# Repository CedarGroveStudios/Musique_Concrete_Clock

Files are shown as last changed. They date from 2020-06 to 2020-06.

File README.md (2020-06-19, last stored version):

# Musique_Concrete_Clock

### RTC-based hybrid cuckoo clock using heirloom sound components, powered by CircuitPython.

Uses a custom Cedar Grove StemmaHost FeatherWing as well as the __CedarGroveStudios/Unit_Converter__ and __CedarGroveStudios/Clock_Builder__ custom CircuitPython libraries.

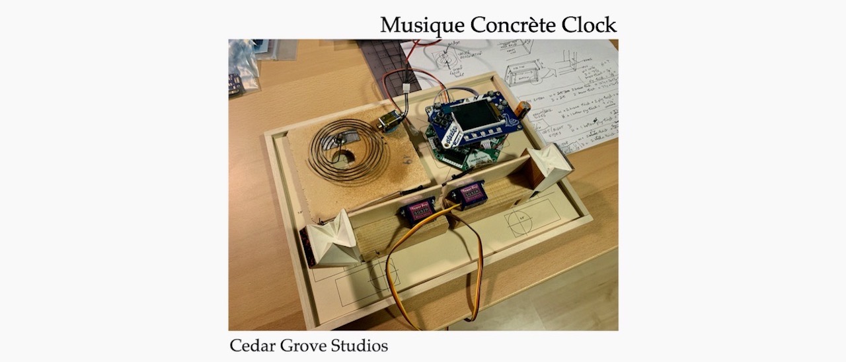
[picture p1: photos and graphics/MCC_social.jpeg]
Musique Concrète Clock


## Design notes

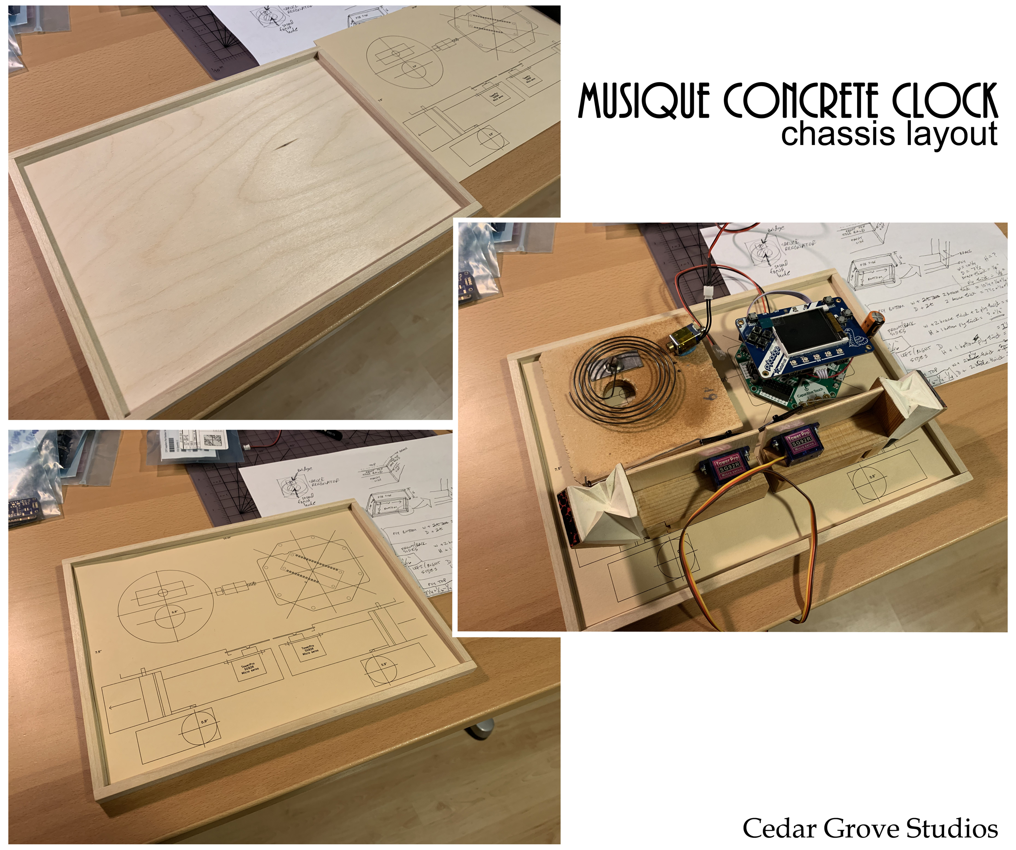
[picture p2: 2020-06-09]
photos and graphics/chassis_combo_a.jpg

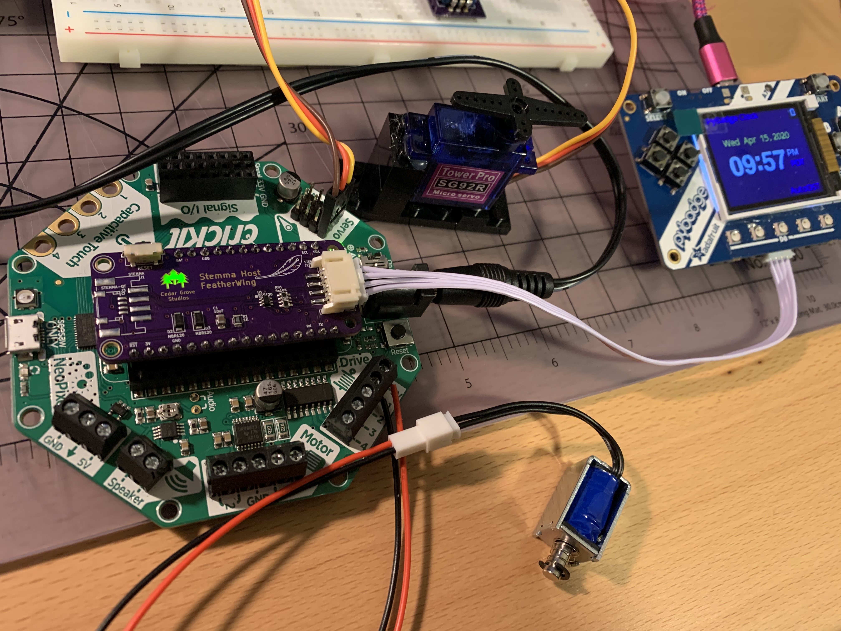
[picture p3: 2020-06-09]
photos and graphics/IMG_0154(Edited).jpg

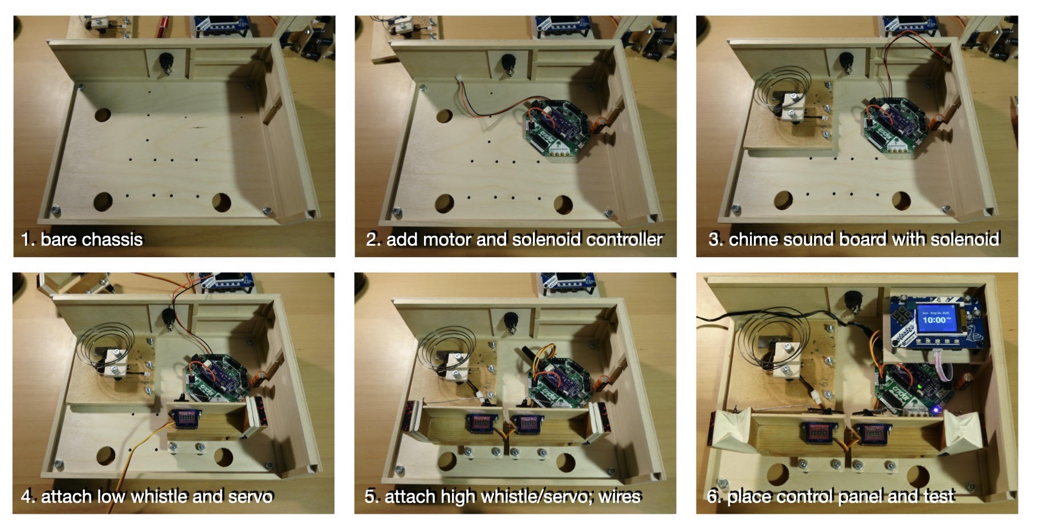
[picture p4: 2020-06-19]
photos and graphics/2020-05-24_MCC_composite.jpeg

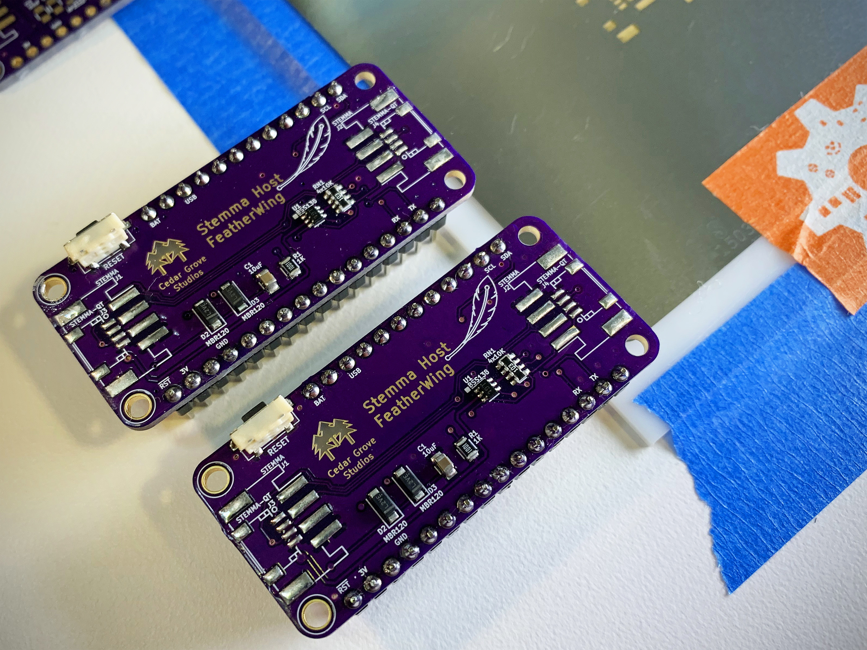
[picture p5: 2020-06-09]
photos and graphics/IMG_0151a.jpg

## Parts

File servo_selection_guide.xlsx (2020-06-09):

Servo Selection Guide
 | Vendor | PID | Price | Make | Model | Size | Gear | Analog FB | Continuous | Deg Rotation | Voltage | Current: Running (mA) | Current: Stall (mA) | Speed (sec/60deg) | Torque (kg-cm) | RPM (no load) | Auto-off
 | Adafruit | 169 | $5.95 | TowerPro | SG92R | Micro | Plastic |  |  | 180 | 4.8v (3-6v) |  |  | 0.10 | 2.50 | 200 | Y
 | Adafruit | 2201 | $5.95 | TowerPro | SG51R | Sub-Micro | Plastic |  |  | 180 | 4.8v (3-6v) |  |  | 0.10 | 0.60 | 200
 | Adafruit | 1143 | $9.95 | TowerPro | MG90D | Micro | Metal |  |  | 90 | 4.8v-6v |  |  | 0.10 | 2.10 | 200 | N
 | Adafruit | 1449 | $9.95 | Datan | S1123 | Micro | Plastic | X |  | 180 | 6v |  |  | 0.10 | 1.60 | 200
 | Adafruit | 1450 | $14.95 | Datan | B2122 | Micro | Metal | X |  | 120 | 6v |  |  | 0.10 | 1.80 | 200
 | Adafruit | 2307 | $11.95 | TowerPro | MG92B | Micro | Metal |  |  | 180 | 5v |  |  | 0.13 | 3.10 | 153.8461538
 | Adafruit | 154 | $11.95 | FeeTech | FS5103R | Standard | ? |  | X |  | 4.8v-6v |  |  | 0.18 | 3.00 | 111.1111111
 | Adafruit | 155 | $12.00 | TowerPro | SG-5010 | Standard | Plastic |  |  | 180 | 4.8v-6v |  |  | 0.20 | 5.50 | 100
 | Adafruit | 1142 | $19.95 | TowerPro | MG995R | Standard | Metal |  |  | 120 | 4.8v-6v |  |  | 0.20 | 8.50 | 100
 | Adafruit | 1404 | $14.95 | Datan | S1213 | Standard | ? | X |  | 180 | ? |  |  | 0.21 | 6.50 | 95.23809524
 | Adafruit | 2442 | $7.50 | TowerPro | FS90R | Micro | Plastic |  | X |  | 4.8v-6v | 100 | 550 |  | 1.30 | 110
 | Adafruit | 3614 | $27.99 | Parallax |  | Standard |  | X | X |  | 6v | 150 | 1200 |  | 2.20 | 120

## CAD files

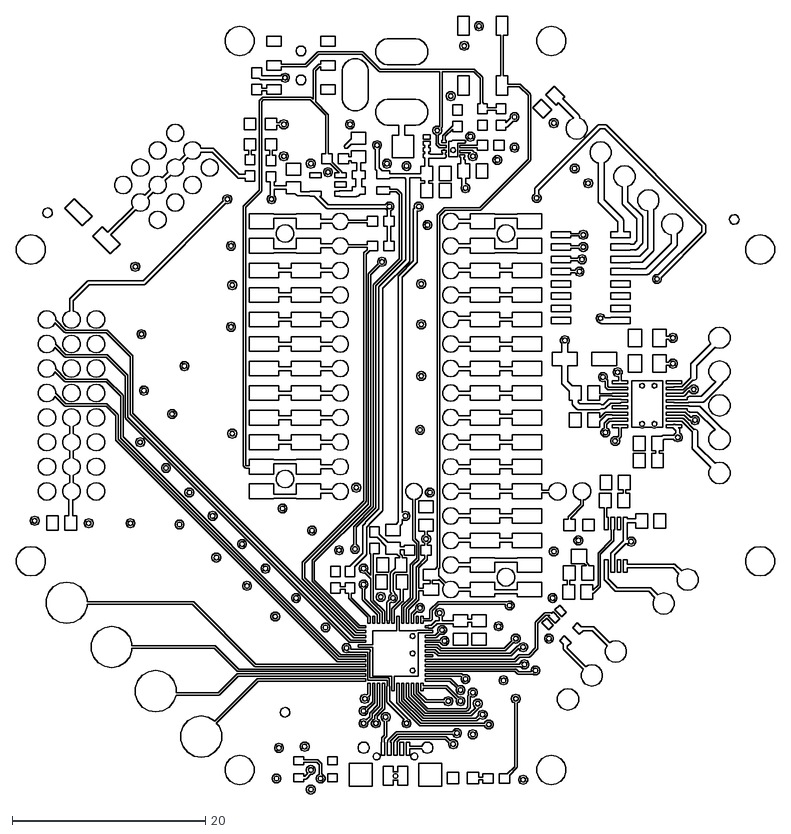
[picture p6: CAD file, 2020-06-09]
MCC_box/Crickit drawings/Adafruit Crickit FeatherWing-Top.dxf
78.4 x 80.5

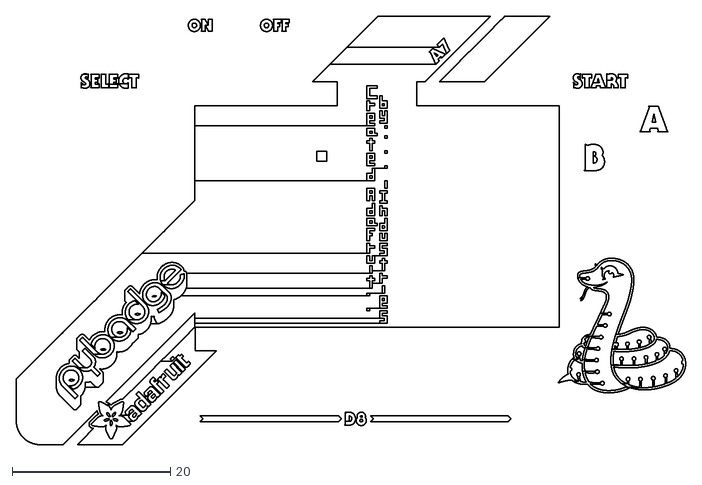
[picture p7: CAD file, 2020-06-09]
MCC_box/PyBadge drawings/Adafruit PyBadge-Dwgs.User.dxf
84.6 x 54.1

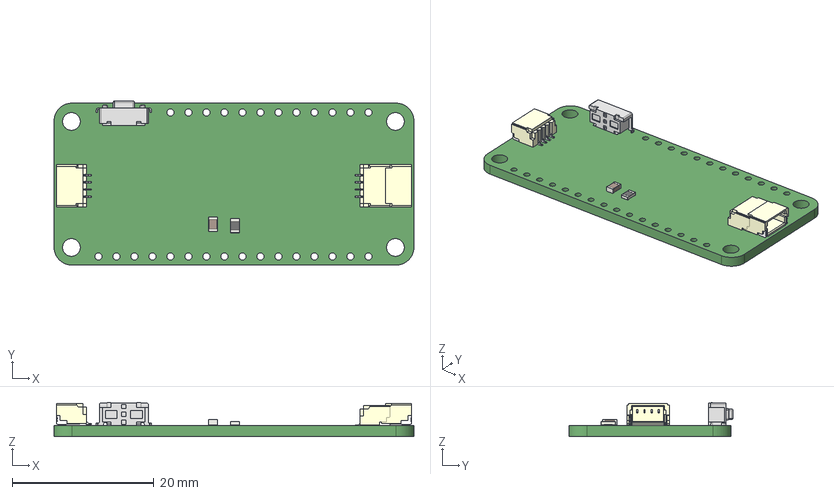
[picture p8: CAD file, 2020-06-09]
PCB/Stemma_Host_FeatherWing.stp
50.8 x 23.2 x 4.85 mm
R_Array_Convex_4x0603
LED_1206
D_SMA_Handsoldering x 2

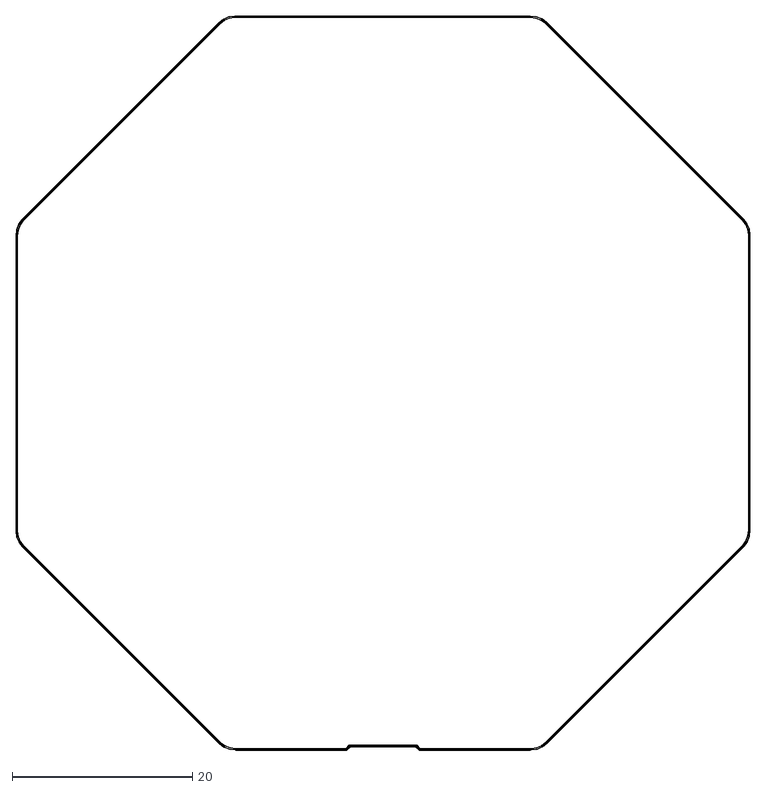
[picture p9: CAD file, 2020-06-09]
MCC_box/Crickit drawings/Adafruit Crickit FeatherWing-Edge.Cuts.dxf
81.4 x 81.4

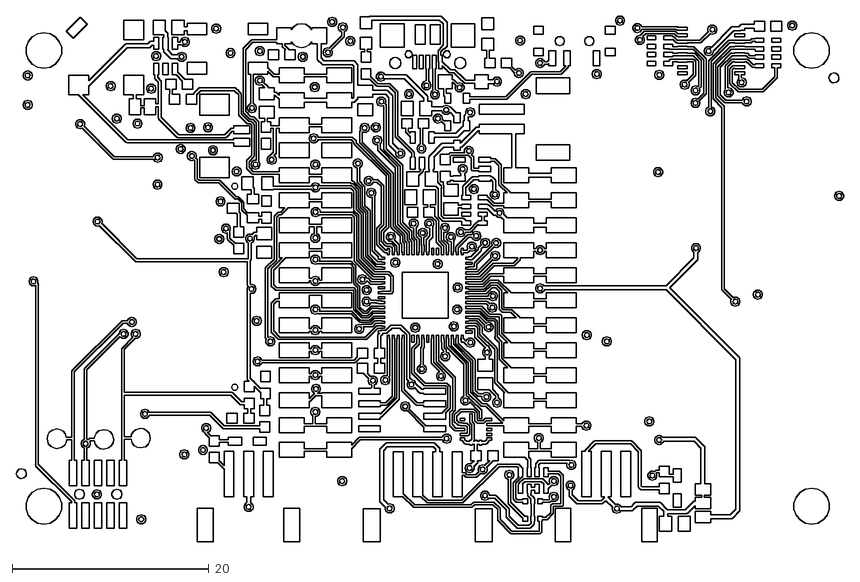
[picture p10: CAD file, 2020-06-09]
MCC_box/PyBadge drawings/Adafruit PyBadge-Top.dxf
84.1 x 53.5

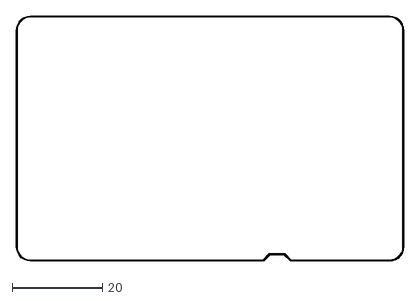
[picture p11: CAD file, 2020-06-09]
MCC_box/PyBadge drawings/Adafruit PyBadge-Edge.Cuts.dxf
85.9 x 54.3

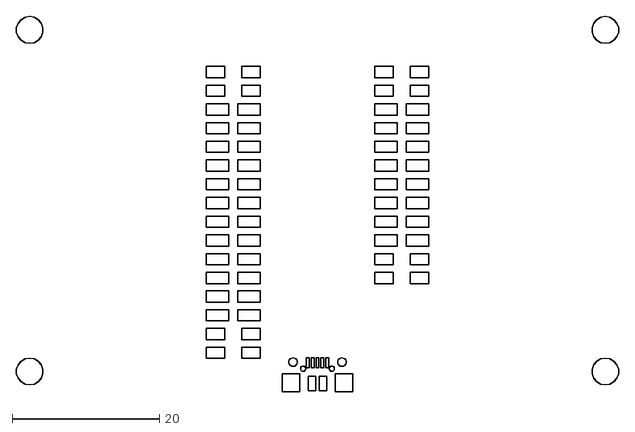
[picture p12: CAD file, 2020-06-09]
MCC_box/PyBadge drawings/Adafruit PyBadge-Bottom.dxf
81.7 x 50.9

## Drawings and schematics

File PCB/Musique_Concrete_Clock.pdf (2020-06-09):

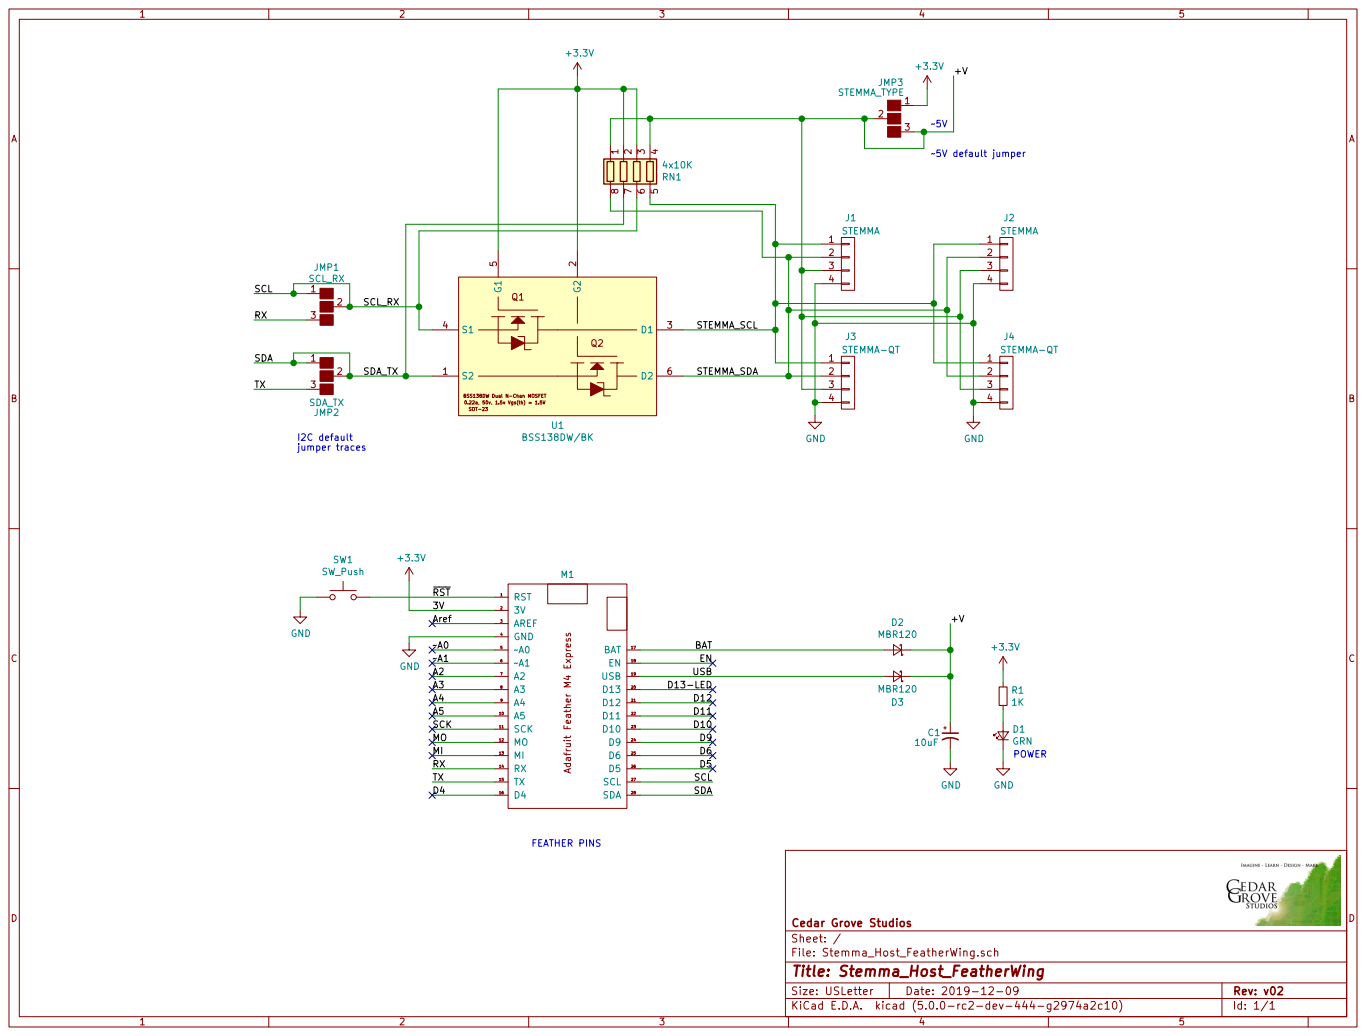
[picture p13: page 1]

File: Stemma_Host_FeatherWing.sch Sheet: / Cedar Grove Studios

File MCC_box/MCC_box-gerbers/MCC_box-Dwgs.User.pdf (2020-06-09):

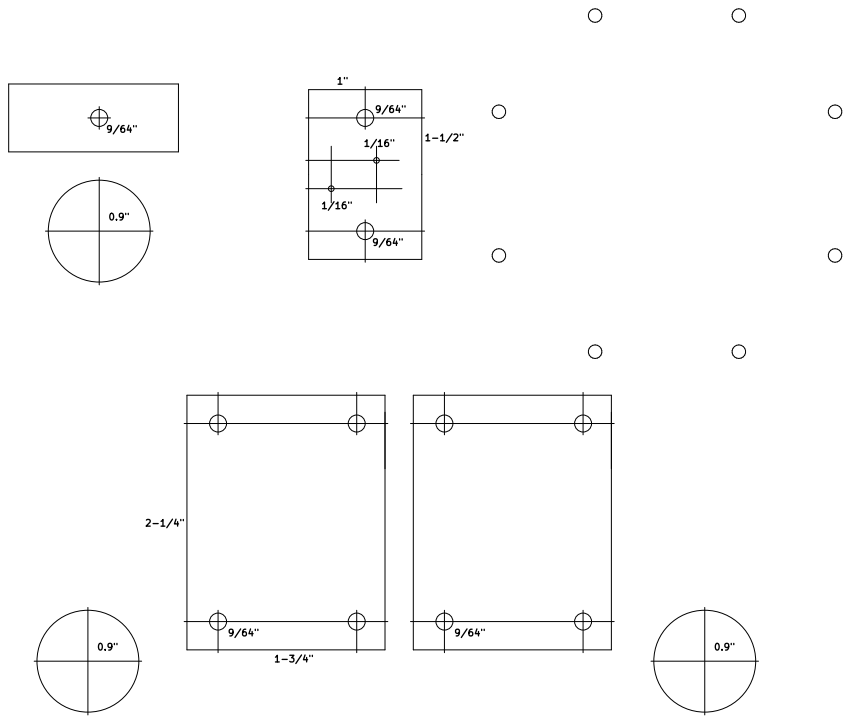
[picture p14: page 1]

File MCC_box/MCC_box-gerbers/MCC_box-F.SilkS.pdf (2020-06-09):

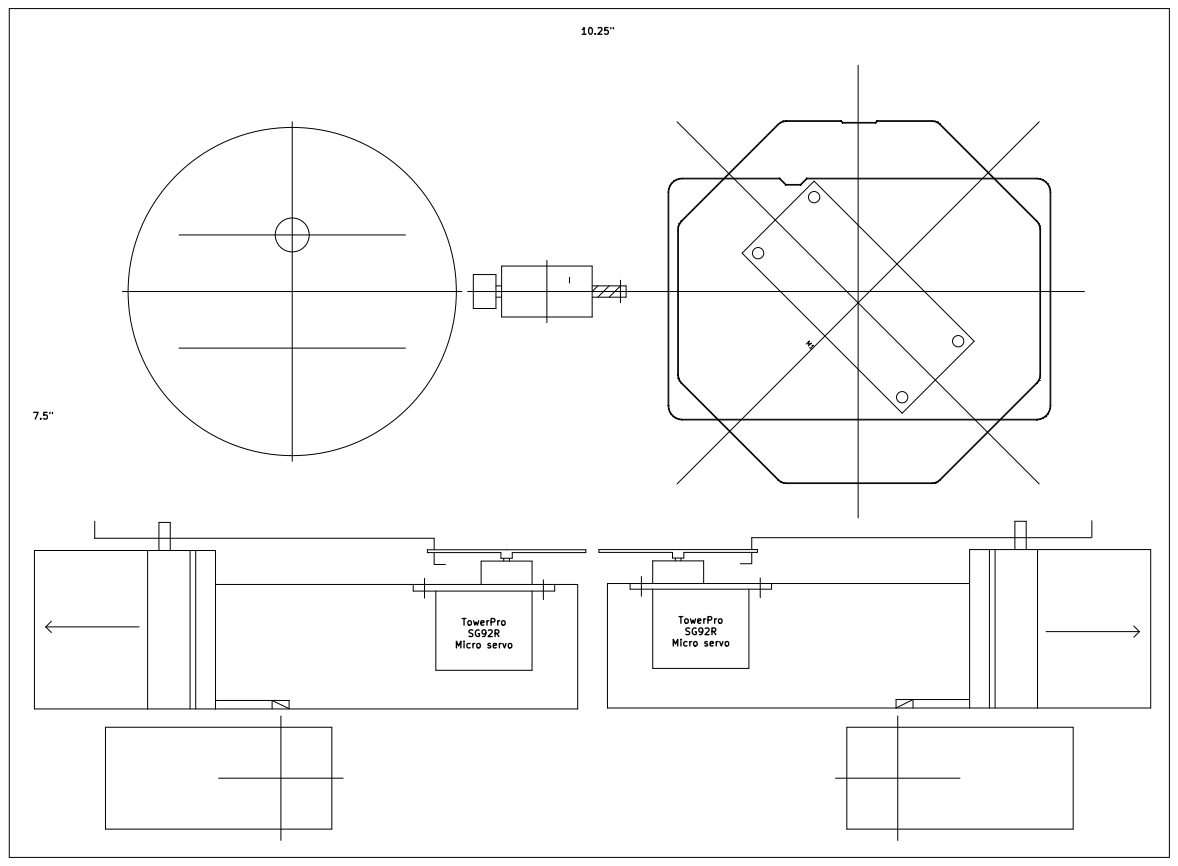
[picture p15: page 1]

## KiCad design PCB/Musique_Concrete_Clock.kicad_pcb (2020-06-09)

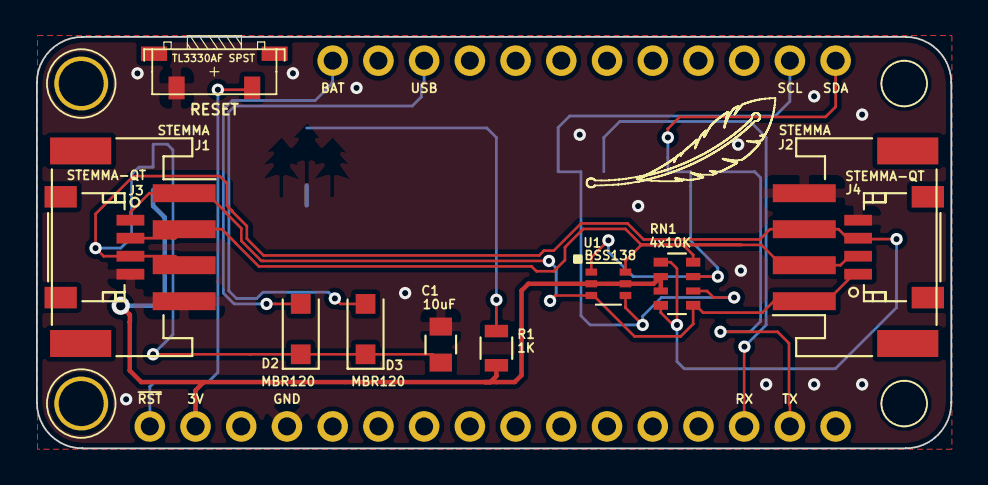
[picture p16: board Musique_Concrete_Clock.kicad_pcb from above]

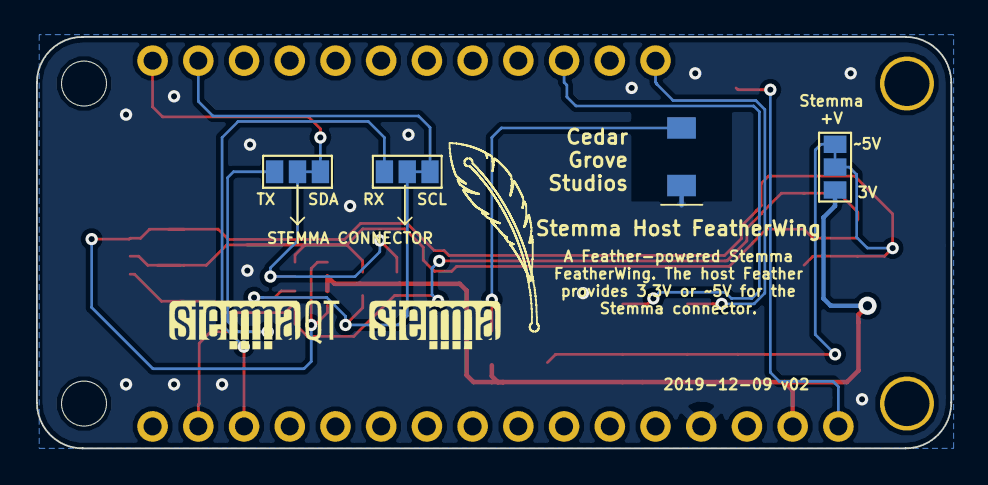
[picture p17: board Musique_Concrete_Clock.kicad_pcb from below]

Board: 2 copper layers, 50.8 x 22.9 mm, 16 parts (3 on the bottom side), 13 nets.

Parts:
C1: 10uF; C_0805
D1: GRN; Cedar_Grove_logo_lighted
D2, D3: MBR120; D_SOD-123F
J1, J2: STEMMA; JST_PH_S4B-PH-SM4-TB_04x2.00mm_Angled
J3, J4: STEMMA-QT; JST_SH_SM04B-SRSS-TB_04x1.00mm_Angled
JMP1: SCL_RX; GS3
JMP2: SDA_TX; GS3
JMP3: STEMMA_TYPE; GS3
M1: Feather_M4_Express; Adafruit_Feather_M4_Express_bare
R1: 1K; R_0805
RN1: 4x10K; R_Array_Convex_4x0603
SW1: RESET; TL3330AF_SPST_BUTTON_RT-ANGLE_7.8mm_2.5mm_2.5mm
U1: BSS138; SOT-363_SC-70-6

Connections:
+3V3: JMP3.1, M1.2, R1.1, RN1.2, RN1.3, U1.2, U1.5
/+V: C1.1, D2.1, D3.1, J1.3, J2.3, J3.3, J4.3, JMP3.2, JMP3.3, RN1.1, RN1.4
/BAT: D2.2, M1.17
/RX: JMP1.3, M1.14
/SCL: JMP1.1, JMP1.2, M1.27, RN1.6, U1.4
/SDA: JMP2.1, JMP2.2, M1.28, RN1.7, U1.1
/STEMMA_SCL: J1.1, J2.1, J3.1, J4.1, RN1.5, U1.3
/STEMMA_SDA: J1.2, J2.2, J3.2, J4.2, RN1.8, U1.6
/TX: JMP2.3, M1.15
/USB: D3.2, M1.19
/~RST: M1.1, SW1.2
GND: C1.2, D1.1, J1.4, J2.4, J3.4, J4.4, M1.4, SW1.1
unnamed: D1.2, R1.2

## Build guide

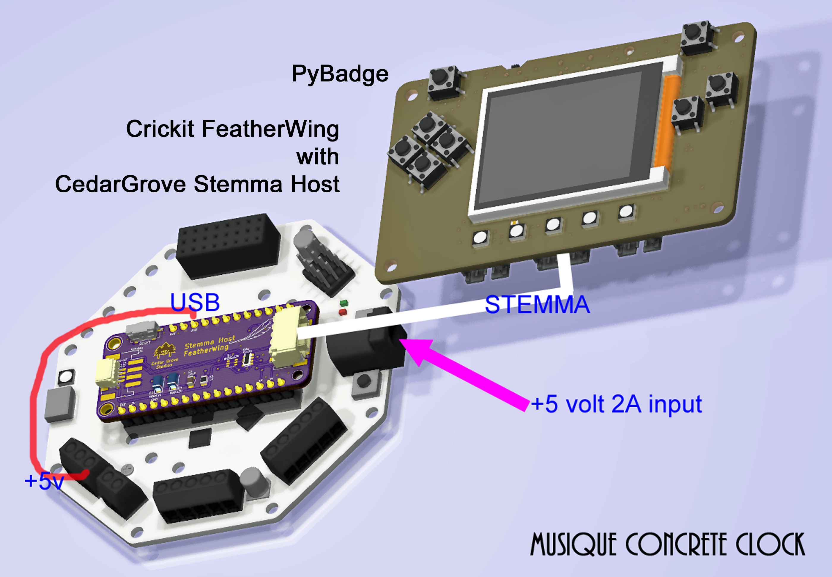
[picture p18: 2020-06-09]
PCB/Musique_Concrete_Clock_wiring.png

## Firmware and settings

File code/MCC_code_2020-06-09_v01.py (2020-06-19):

# MCC_code_2020-06-09_v01.py
# Cedar Grove Studios
# uses Robot_Friend_FeatherWing.cedargrove_pypanel.py
# uses cedargrove unit_converter library
# uses cedargrove clock_builder library (display, set_time, chime)

import time
import board
import adafruit_ds3231
from   analogio                      import AnalogIn
from   unit_converter.chronos        import adjust_dst
from   cedargrove_clock_builder.repl_display    import ReplDisplay
from   cedargrove_clock_builder.pybadge_display import PyBadgeDisplay  # PyBadge display
from adafruit_crickit import crickit

i2c = board.I2C()
ds3231 = adafruit_ds3231.DS3231(i2c)

batt = AnalogIn(board.A6)
print("Battery: {:01.2f} volts".format((batt.value / 65520) * 6.6))

### SETTINGS ###
clock_display  = ["pybadge", "repl"]  # List of active display(s)
clock_zone     = "Pacific"  # Name of local time zone
clock_24_hour  = False      # 24-hour clock = True; 12-hour AM/PM = False
clock_auto_dst = True       # Automatic US DST = True
clock_sound    = True       # Sound is active
clock_tick     = True       # One-second tick sound

servo_1_start    = 70         # Resting servo position
servo_1_end      = 140        # Active servo position
servo_2_start    = 140         # Resting servo position
servo_2_end      = 70        # Active servo position

### Instatiate display

# PyBadge display
pybadge_disp  = PyBadgeDisplay(clock_zone, clock_24_hour, clock_auto_dst,
                               clock_sound, brightness=0.5, debug=False)

pybadge_disp.battery = (batt.value / 65520) * 6.6

#  REPL display
repl_disp = ReplDisplay(clock_zone, clock_24_hour, clock_auto_dst,
                        clock_sound, debug=False)

### Instatiate Crickit
from adafruit_crickit import crickit
crickit.init_neopixel(1, brightness=0.01) # must call this first
crickit.onboard_pixel.brightness = 0.01
crickit.onboard_pixel[0] = (0, 255, 0)  # green for startup

# Energize the power indicator
crickit.feather_drive_2.fraction = 0.5  # power indicator

### Instatiate whistle servos
# reset servo to start position and disable
crickit.servo_1.angle = servo_1_start
crickit.servo_2.angle = servo_2_start
time.sleep(0.25)
crickit.servo_1.angle = None  # disable servo
crickit.servo_2.angle = None
time.sleep(0.5)

"""# calibrate servos at end position and disable
crickit.servo_1.angle = servo_1_end
crickit.servo_2.angle = servo_2_end
time.sleep(0.25)
crickit.servo_1.angle = None  # disable servo
crickit.servo_2.angle = None
time.sleep(0.5)
while True:
    pass"""

### HELPERS ###
def chime(hour, solenoid_hold=0.010, servo_hold=0.200,
          start_1=servo_1_start, end_1=servo_1_end,
          start_2=servo_2_start, end_2=servo_2_end):  # play chime and cuckoo n cycles
    crickit.servo_1.angle = start_1  # wake up servo and move to start
    crickit.servo_2.angle = start_2
    time.sleep(servo_hold)

    if hour > 12:
        hour = hour - 12
    if hour  == 0:  # midnight hour fix
        hour = 12

    for i in range(0, hour):
        crickit.feather_drive_1.fraction = 1.0  # chime
        time.sleep(solenoid_hold)
        crickit.feather_drive_1.fraction = 0.0
        time.sleep(servo_hold * 2)

        crickit.servo_1.angle = end_1  # cu
        time.sleep(servo_hold)
        crickit.servo_1.angle = start_1

        crickit.servo_2.angle = end_2    # coo
        time.sleep(servo_hold)
        crickit.servo_2.angle = start_2
        time.sleep(servo_hold)

    crickit.servo_1.angle = None  # disable servo
    crickit.servo_2.angle = None
    time.sleep(servo_hold)

# test the chimes
crickit.onboard_pixel[0] = (255, 0, 0)  # red for chime test
chime(1)

crickit.onboard_pixel[0] = (255, 24, 255)  # purple for normal operation

# Manually set time upon RTC power failure
if ds3231.lost_power:
    print("--RTC POWER FAILURE--")
    # Set time with REPL
    # ds3231.datetime = repl_disp.set_datetime()

    # Set time with PyBadge
    pybadge_disp.show(ds3231.datetime)
    pybadge_disp.message = "-RTC POWER FAILURE-"

min_flag = half_flag = hour_flag = False

# initiate pybadge display contents
if "pybadge" in clock_display:
    # Check datetime and adjust if DST
    if clock_auto_dst:             # read the RTC and adjust for DST
        current, is_dst = adjust_dst(ds3231.datetime)
    else:
        current = ds3231.datetime  # otherwise, just read the RTC
        is_dst = False

    pybadge_disp.dst = is_dst
    pybadge_disp.show(current)

while True:
    if pybadge_disp.panel.button.b:  # To test whistles and gong
        chime(1)

    # Check datetime and adjust if DST
    if clock_auto_dst:             # read the RTC and adjust for DST
        current, is_dst = adjust_dst(ds3231.datetime)
    else:
        current = ds3231.datetime  # otherwise, just read the RTC
        is_dst = False

    # update REPL display
    if "repl" in clock_display:
        repl_disp.dst = is_dst
        repl_disp.show(current)

    # update led display
    if "led" in clock_display:
        led_disp.dst    = is_dst
        led_disp.colon  = not led_disp.colon
        led_disp.show   = current  # refresh LED display

    if "pybadge" in clock_display:
        pybadge_disp.colon  = not pybadge_disp.colon  # auto-refresh

        # Check to see if time was set
        new_xst_datetime, clock_sound, update_flag = pybadge_disp.set_datetime(ds3231.datetime)
        if update_flag:  # If so, update RTC Std Time with new datetime
           ds3231.datetime = new_xst_datetime
           print("RTC time was set")

    # play tick sound
    if clock_sound and clock_tick:
        pybadge_disp.tick()

    if pybadge_disp.panel.light < 5000:
        pybadge_disp.panel.brightness = 0.025
        crickit.feather_drive_2.fraction = 0.05  # power indicator
    else:
        pybadge_disp.panel.brightness = 0.5
        crickit.feather_drive_2.fraction = 0.5  # power indicator

    # Do something every minute
    if current.tm_sec == 0 and not min_flag:
        # do something here
        print("every MIN")

        print("Battery: {:01.2f} volts".format((batt.value / 65520) * 6.6))

        # update PyBadge display
        if "pybadge" in clock_display:
            pybadge_disp.dst = is_dst
            pybadge_disp.show(current)
            pybadge_disp.battery = (batt.value / 65520) * 6.6

        min_flag = True
    elif current.tm_sec > 0:
        min_flag = False

    # Do something every half-hour
    if current.tm_min == 30 and not half_flag:
        # do something here
        print("every HALF")
        chime(1)
        half_flag = True
    elif current.tm_min > 30:
        half_flag = False

    # Do something every hour
    if current.tm_min == 0 and not hour_flag:
        # do something here
        print("every HOUR")
        chime(current.tm_hour)
        hour_flag = True
    elif current.tm_min > 0:
        hour_flag = False

    # wait a second before looping
    prev_sec = current.tm_sec
    while current.tm_sec == prev_sec:  # wait a second before looping
        current = ds3231.datetime
